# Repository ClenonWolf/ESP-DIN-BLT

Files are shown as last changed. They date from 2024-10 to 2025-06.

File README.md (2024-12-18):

# ESP-DIN-BLT
An ESP32 Bluetooth module with autoplay for single din height car stereo mount based on the [ESP32-A2DP library](https://github.com/pschatzmann/ESP32-A2DP). Including a Partslist and 3D models for mounting. Unfortunately I only noticed that the slot for my Car turned out to not be a standard DIN and therefore modelled it after that. I will try to create universal models for normal DIN units so that this can also be used in other cars. Let me know if you need one before I've come around to modelling it.

Documentation is ongoing and not done yet.
If any mistakes or code improvements are found, please let me know. I'm new to C++ and therefore the code could probably be improved upon by a lot.

## To-Do
- Ground loop isolation (Ongoing)
- ~~Improve button input system // Fix Play/Pause button not responding~~ Fixed but could be implemented nicer.
- Gerber files and custom PCB (maybe)

## Known issues
- Play/Pause delayed from `a2dp_sink.get_audio_state()` being slow

## Images



Please don't judge me for using flash. It was too dark outside at the time.

## Hardware used
- [ESP-Wroom-32](https://amzn.eu/d/bhH6WHx)
- [PCM5102 DAC](https://amzn.eu/d/hkPHz4O)
- [LM2596 Buck Converter](https://amzn.eu/d/bHiczJB)
- [12mm Push Button](https://amzn.eu/d/4PPdXcS)
- [12mm Locking Push Button](https://amzn.eu/d/iBPg1n6)
- [Two Position Switch 6 Terminals](https://amzn.eu/d/7hplkBi)
- [Threaded Inserts](https://amzn.eu/d/7x8pk4a)
- [Pin Headers as Socket](https://amzn.eu/d/j3ADpWZ)
- Perfboard
- Random Wire
- Some sort of connectors (Optional)

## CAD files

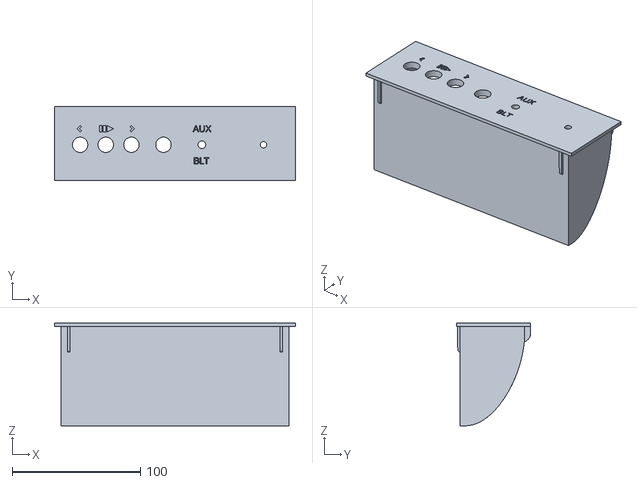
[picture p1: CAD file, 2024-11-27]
3D Models/Mercedes A140 W196/Mercedes A140 W196 v12.stl
188.0 x 58.0 x 80.0

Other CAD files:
3D Models/Mercedes A140 W196/Mercedes A140 W196 v12.f3d

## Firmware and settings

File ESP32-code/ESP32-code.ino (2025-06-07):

#include "ESP_I2S.h"
#include "BluetoothA2DPSink.h"

//pin configuration
const uint8_t I2S_SCK = 5;       // Audio data bit clock 
const uint8_t I2S_WS = 25;       // Audio data left and right clock
const uint8_t I2S_SDOUT = 26;    // ESP32 audio data output to DAC
const uint8_t prevbutton = 13;   //self explainatory
const uint8_t nextbutton = 14;
const uint8_t playbutton = 12;
const uint8_t autobutton = 27;   //Latching button that enables autoplay on reconnect
volatile byte playpause = LOW;   //Volatile byte values for the ISRs
volatile byte prev = LOW;
volatile byte next = LOW;

I2SClass i2s;
BluetoothA2DPSink a2dp_sink(i2s);

void setup() {
    Serial.begin(115200);                   //Start serial connection for debugging purposes
    pinMode(prevbutton, INPUT_PULLUP);      //Setting pinModes
    pinMode(nextbutton, INPUT_PULLUP);
    pinMode(playbutton, INPUT_PULLUP);
    pinMode(autobutton, INPUT_PULLUP);
    attachInterrupt(digitalPinToInterrupt(prevbutton), ISR0, FALLING); //Starting interrupts for specified pins  
    attachInterrupt(digitalPinToInterrupt(playbutton), ISR1, FALLING);
    attachInterrupt(digitalPinToInterrupt(nextbutton), ISR2, FALLING);
    
    //Configuring i2s
    Serial.println("starting I2S-ADC...");
    i2s.setPins(I2S_SCK, I2S_WS, I2S_SDOUT); 
    if (!i2s.begin(I2S_MODE_STD, 44100, I2S_DATA_BIT_WIDTH_16BIT, I2S_SLOT_MODE_STEREO, I2S_STD_SLOT_BOTH)) {
      Serial.println("Failed to initialize I2S!");
      while (1);
    }
    a2dp_sink.set_auto_reconnect(true);     //enable auto reconnect. Probably not neccecary as I'm using a reconnect loop
    a2dp_sink.start("Music thingy :3");     //start a2dp_sink and specify device name
}

//Defining the ISRs for each button
//I hate the way I did the debounce
void ISR0() {
  static unsigned long last_interrupt_time = 0;
  unsigned long interrupt_time = millis();
  // If interrupts come faster than 200ms, assume it's a bounce and ignore
  if (interrupt_time - last_interrupt_time > 500) 
  {
    prev = HIGH;
  }
  last_interrupt_time = interrupt_time;
  }
void ISR1() {
  static unsigned long last_interrupt_time = 0;
  unsigned long interrupt_time = millis();
  if (interrupt_time - last_interrupt_time > 500) 
  {
    playpause = HIGH;
  }
  last_interrupt_time = interrupt_time;
  }
void ISR2() {
  static unsigned long last_interrupt_time = 0;
  unsigned long interrupt_time = millis();
  if (interrupt_time - last_interrupt_time > 500) 
  {
    next = HIGH;
  }
  last_interrupt_time = interrupt_time;
  }

void loop() {
  //Reconnect if disconnected
  if(a2dp_sink.is_connected() == false){
    while(a2dp_sink.is_connected() == false){
      Serial.println("Attempting to reconnect with last device");
      a2dp_sink.reconnect();
      delay(1000);
      Serial.println("waiting for connection...");
    }
    a2dp_sink.set_volume(127);
    //Autoplay if autoplay-button is latched on
    if((digitalRead(autobutton) == 0) ) {
      Serial.println("Play on reconnect after delay");
      delay(5000);                                      //Generous delay as buffer, otherwise play command is sent before fully connected. Could probably be lowered down all the way to a second
      a2dp_sink.play();
      Serial.println("Play!");
    }
  }

  //Button actions from the ISRs
  if(prev == HIGH) {
    Serial.println("Previous");
    a2dp_sink.previous();
    prev = LOW;
  }
  if(next == HIGH) {
    Serial.println("Next");
    a2dp_sink.next();
    next = LOW;
  } 
  if(playpause == HIGH){
    if(a2dp_sink.get_audio_state() == 0) {    //Check if audio is playing, if not button functionality is play
      Serial.println("Play");
      a2dp_sink.play();
    }
    else{                                     //If audio is playing (Otherwise), button functionality is pause
      Serial.println("Pause");
      a2dp_sink.pause();
    }
    playpause = LOW;
  }

  //Causes audio issues if not used. Probably CPU usage 
  delay(100);
}

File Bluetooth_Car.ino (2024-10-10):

#include "ESP_I2S.h"
#include "BluetoothA2DPSink.h"

const uint8_t I2S_SCK = 5;       /* Audio data bit clock */
const uint8_t I2S_WS = 25;       /* Audio data left and right clock */
const uint8_t I2S_SDOUT = 26;    /* ESP32 audio data output (to speakers) */
const uint8_t prevbutton = 13;
const uint8_t nextbutton = 14;
const uint8_t playbutton = 12;
const uint8_t autobutton = 27;
int8_t IntStat = 0;
int pbuttonstate = 0; //Play button state for state change detection / edge detection
int lastpbuttonstate = 0;
I2SClass i2s;

BluetoothA2DPSink a2dp_sink(i2s);

void setup() {
    Serial.begin(115200);
    pinMode(prevbutton, INPUT_PULLUP);
    pinMode(nextbutton, INPUT_PULLUP);
    pinMode(playbutton, INPUT_PULLUP);
    pinMode(autobutton, INPUT_PULLUP);

    Serial.println("starting I2S-ADC...");
    i2s.setPins(I2S_SCK, I2S_WS, I2S_SDOUT);
    if (!i2s.begin(I2S_MODE_STD, 44100, I2S_DATA_BIT_WIDTH_16BIT, I2S_SLOT_MODE_STEREO, I2S_STD_SLOT_BOTH)) {
      Serial.println("Failed to initialize I2S!");
      while (1); // do nothing
    }
    a2dp_sink.set_auto_reconnect(true);
    a2dp_sink.start("Music thingy :3");
}
void loop() {

  //Reconnect if disconnected
  if(a2dp_sink.is_connected() == false){
    while(a2dp_sink.is_connected() == false){
      Serial.println("Attempting to reconnect with last device");
      a2dp_sink.reconnect();
      delay(1000);
      Serial.println("waiting for connection...");
    }
    //Autoplay if autoplay-button is latched on
    if((digitalRead(autobutton) == 0) ) {
      Serial.println("Play on reconnect after delay");
      delay(5000);                                      //Generous delay as buffer, otherwise play command is sent before fully connected. Could probably be lowered down all the way to a second
      a2dp_sink.play();
      Serial.println("Play!");
    }
  }

  //Didn't implement edge detection for prev/next buttens for simplicity reasons
  //Not strictly neccesary as it doesn't cause noticable issues
  if(digitalRead(prevbutton) == 0) {
    a2dp_sink.previous();
  }
  if(digitalRead(nextbutton) == 0) {
    a2dp_sink.next();
  }

  //Play button has edge detection as the same button is used for play/pause
  pbuttonstate = digitalRead(playbutton);
  if(pbuttonstate != lastpbuttonstate){ 
    if(pbuttonstate == HIGH){
      if(a2dp_sink.get_audio_state() == 0) {    //Check if audio is playing, if not button functionality is play. Check takes kinda long for a button press, maybe improve (button needs to be pressed kinda long)
        a2dp_sink.play();
      }
      else{                                     //If audio is playing (Otherwise), button functionality is pause
        a2dp_sink.pause();
      }
    }
  }
  lastpbuttonstate = pbuttonstate;

  //Delay as a sort of debounce. Also causes audio issues if not used which is probably caused by the reconnect loop 
  delay(20);
}

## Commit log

2024-10-10 Update ESP32-code.ino
    Adding comments
    cleaning up
2024-10-10 Update ESP32-code.ino
    Further cleaning up and stuff
2024-11-27 Adding 3D files
    [Mercedes A140 W196 v12.f3d, Mercedes A140 W196 v12.stl]
2024-11-27 Adding Schematic folder as reminder to myself
2024-11-28 Add Schmatic
    [ESP-DIN-BLT.kicad_sch]
2024-12-11 Implementing buttons as interrupts
